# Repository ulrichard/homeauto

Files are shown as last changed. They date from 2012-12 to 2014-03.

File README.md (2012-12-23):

homeauto
========

Remote control power switches from a simple web application.

All you need is :
* Remote switched power plugs that operate at 433MHz
* AtTiny45 http://www.conrad.ch/ce/de/product/154219/
* 433MHz transmitter http://dx.com/p/433mhz-wireless-transmitter-module-superregeneration-for-arduino-green-149254
* A small linux (preferrably debian) device that has ic2 available and can run python. For example: 
		* I use an alix http://pcengines.ch
    	* Also tested with a RaspberryPi http://raspberrypi.org
		* Bifferboard http://bifferos.co.uk/

First flash the code in the directory tiny_i2c_433 onto an AtTiny. The main file RemoteSwitch.c documents how to connect it to the transmitter and the i2c bus.
Once you connected it to the i2c bus of your small linux device, run the python web app homeSwitchWeb.py. It will run on port 5000.
You will have to adjust some settings such as i2c bus address, and rf adressing to match your devices. But it's very simple.

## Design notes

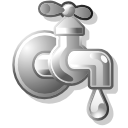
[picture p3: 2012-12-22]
static/C_0.png

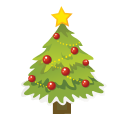
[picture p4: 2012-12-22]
static/B_1.png

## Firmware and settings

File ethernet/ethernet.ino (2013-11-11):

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
#include "IR.h"
#include "nokia3310lcd.h"
#include <EncEthernet.h>
#include <Arduino.h>
#include <Wire.h>
#include <SPI.h>

//  AtMega 328
//                      +-\/-+
//              RST -> 1|    |28 <-  SCL  -------------- C  I
//         uart RXD -> 2|    |27 <-> SDA  -------------- D  2
//         uart TXD <- 3|    |26                   +---- V  C
//  ENC28J60 INT -- D2 4|    |25                   |  +- G 
//      LED red  <- D3 5|    |24                   |  |   nokia 5110 LCD
//                  D4 6|    |23 -> backlight --+  |  |  +--------------+
//                VCC  7|    |22  GND ----------|--|--+--|        GND ->|
//                GND  8|    |21                +--|-----|  backlight ->|
//            crystal  9|    |20  VCC     ---------+-----|        VCC ->|
//            crystal 10|    |19 D13 -> SCK--------------|        SCK ->|  x-> ENC28J60 SCK
//                    11|    |18 D12 <- MISO  +----------|       MOSI ->|  x-> ENC28J60 SO
//                    12|    |17 D11 -> MOSI -+     +----|   cmd/data ->|  x-> ENC28J60 SI
// LCD chip select <- 13|    |16 D10 <- SS          | +--|chip enable ->|  x-> ENC28J60 CS
// LCD reset  |   +-<-14|    |15 D9 -> LCD cmd/data-+ |+-|      reset ->|
//            |   |     +----+                        || +--------------+                  
//            +---|-----------------------------------+|
//                +------------------------------------+  
//
// ENC28J60 Ethernet adapter -> connections from top:
// http://www.geeetech.com/wiki/index.php/Arduino_ENC28J60_Ethernet_Module
// 
// 	  CLK out  |  INT
//	      SOL  |  SO
//         SI  |  SCK
//         CS  |  reset
//        VCC  |  GND

// the mac and ip of the Arduino Ethernet shield
byte mac[] = {0xDE, 0xAD, 0xBE, 0xEF, 0xFE, 0xED};
byte ip[]  = {192, 168, 2, 9};

// Enter the IP address of the web server
byte ulrichardIp[] = {192, 168, 2, 7}; // ulrichard.ch

// pin assignments
static const uint8_t PIN_status_LED = 3;
static const uint8_t PIN_IR_LED     = 9; // OC1A -> infrared transmitter LED.
static const uint8_t LCD_BACKLIGHT  = A0;

EncServer server(80); // Port 80 is http
EncClient ulrichardClient(ulrichardIp, 9332);
Nokia3310LCD  disp(9, 8, 7);

char linebuf[128];
uint16_t linepos;

void setup()
{
	Serial.begin(115200);

	EncEthernet.begin(mac, ip);
	server.begin();

	pinMode(LCD_BACKLIGHT, OUTPUT);
    digitalWrite(LCD_BACKLIGHT, LOW);

//	SPI.begin();
//	SPI.setClockDivider(SPI_CLOCK_DIV64); // 250 kHz

	disp.init();
    disp.LcdContrast(0x40);
	disp.LcdClear();
	disp.LcdGotoXYFont(1, 1);
	disp.LcdStr(Nokia3310LCD::FONT_1X, "hello world");
	disp.LcdUpdate();

//	IR::initialise(0); // IR receiver hardware is on pin2. -> conflicting with ethernet

	pinMode(4, OUTPUT);
	digitalWrite(4, LOW);
	// blink to show we're alive
	pinMode(PIN_status_LED, OUTPUT);
	digitalWrite(PIN_status_LED, HIGH);
	delay(500);
	digitalWrite(PIN_status_LED, LOW);
	delay(500);
	digitalWrite(PIN_status_LED, HIGH);
	delay(500);
	digitalWrite(PIN_status_LED, LOW);
}

void loop()
{
/* -> pin conflicting with ethernet
	// Check if we received some IR code 
	if(!IR::queueIsEmpty())
	{
		digitalWrite(PIN_status_LED, HIGH);
		Serial.println("____");

		IR_COMMAND_TYPE code;
		while(IR::queueRead(code))
		{
			Serial.print("IR: ");
			Serial.println(code, DEC);
		}
		digitalWrite(PIN_status_LED, LOW);
	}
*/

/* first testing the client part
	// Check if we received something over ethernet
	EncClient client = server.available();
	if(client)
	{
//		Serial.println("____");
//		Serial.println("Web: ");

		// an http request ends with a blank line
		boolean current_line_is_blank = true;
		while(client.connected())
		{
			disp.LcdClear();
			uint8_t x = 1, y = 1;

			if(client.available())
			{
				const char c = client.read();
				// if we've gotten to the end of the line (received a newline
				// character) and the line is blank, the http request has ended,
				// so we can send a reply
				if(c == '\n' && current_line_is_blank)
				{
					// send a standard http response header
					client.println("HTTP/1.1 200 OK");
					client.println("Content-Type: text/html");
					client.println();

					// output the value of each analog input pin
					for(int i = 0; i < 6; i++)
					{
						client.print("analog input ");
						client.print(i);
						client.print(" is ");
						client.print(analogRead(i));
						client.println("");
					}
					break;
				}
				if(c == '\n')
				{
					// we're starting a new line
					current_line_is_blank = true;

//					Serial.println("");

					x = 1;
					++y;
				}
				else if(c != '\r')
				{
					// we've gotten a character on the current line
					current_line_is_blank = false;

//					Serial.print(c);
					disp.LcdGotoXYFont(x, y);
					disp.LcdChr(Nokia3310LCD::FONT_1X, c);
				}
			}
			disp.LcdUpdate();
		}
		// give the web browser time to receive the data
		delay(1);
		client.stop();
	}
*/

	// Check the state of the bitcoin miner
	// https://en.bitcoin.it/wiki/P2Pool#Web_interface
	linepos = 0;
	bool foundPrev = false, foundColon = false;
	uint32_t hashrate = 0;
	while(ulrichardClient.connected())
	{
		digitalWrite(PIN_status_LED, LOW);

		if(!ulrichardClient.available())
			continue;
		const char c = ulrichardClient.read();

		if('\n' == c)
		{
			linebuf[linepos++] = '\0';

			if(0 == hashrate)
			{
				disp.LcdGotoXYFont(1, 1);
				disp.LcdStr(Nokia3310LCD::FONT_1X, linebuf);
				disp.LcdUpdate();
			}

			if(foundColon)
			{
				hashrate = atoi(linebuf);         // in H/s
				hashrate /= (1024 * 1024 * 1024); // GH/s

				sprintf(linebuf, "%d GH/s", hashrate);

				disp.LcdGotoXYFont(1, 1);
				disp.LcdStr(Nokia3310LCD::FONT_1X, linebuf);
				disp.LcdUpdate();

				foundColon = foundPrev = false;
			}
			else if(strncmp("miner_hash_rates", linebuf, 16))
				foundPrev = true;


			linepos = 0;
		}
		else if('\r' == c)
			continue;
		else if(0 == linepos && (' ' == c || '*' == c || '\"' == c))
			continue; // trim left
		else if(foundPrev && !foundColon)
		{
			if(':' == c)
				foundColon = true;
			continue;
		}
		else if(linepos + 2 < sizeof(linebuf))
			linebuf[linepos++] = c;
	}
	ulrichardClient.stop();
	delay(10);
		 
	if(ulrichardClient.connect())
	{
		digitalWrite(PIN_status_LED, LOW);
//		Serial.println("ulrichard.ch reachable");

		ulrichardClient.println("GET /local_stats HTTP/1.1");
		ulrichardClient.println("Host: 192.168.2.7:9332");
		ulrichardClient.println();

		
	}
	else
	{
		digitalWrite(PIN_status_LED, HIGH);
//		Serial.println("no connection to ulrichard.ch");

		disp.LcdClear();
		disp.LcdGotoXYFont(1, 1);
		disp.LcdStr(Nokia3310LCD::FONT_1X, "could not");
		disp.LcdGotoXYFont(1, 2);
		disp.LcdStr(Nokia3310LCD::FONT_1X, "connect to");
		disp.LcdGotoXYFont(1, 3);
		disp.LcdStr(Nokia3310LCD::FONT_1X, "ulrichard.ch:9332");
		disp.LcdUpdate();
	}
	

}

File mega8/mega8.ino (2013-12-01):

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
// This program will serve as an interface between the
// the i2c bus and a simple 433MHz transmitter.
// It exposes commands to switch wall plugs
// Created by Richard Ulrich <richi@paraeasy.ch>
// Inspired by :


// ATMEL AtMega8
//                       +-\/-+
//                      1|    |8  Vcc
//                      2|    |7 <-  I2C_SCL
//              test -> 3|    |6  -> 433MHz transmitter
//               GND    4|    |5 <-> I2C_SDA
//                       +----+

#include <inttypes.h>
#include "usiTwiSlave.h"
#include "RemoteTransmitter.h"
#include <avr/io.h>
#include <util/delay.h>
#include <avr/interrupt.h>
#include <avr/eeprom.h>

uint8_t  EEMEM i2cSlaveAddr = 0x11; // Default address

int main(void)
{
	_delay_ms(100); // give the master some time to grab the i2c bus
	sei(); 			// enable interrupts
	if(eeprom_read_byte(&i2cSlaveAddr) < 7 || eeprom_read_byte(&i2cSlaveAddr) > 77)
		eeprom_write_byte(&i2cSlaveAddr, 0x11);
	usiTwiSlaveInit(eeprom_read_byte(&i2cSlaveAddr)); // initialize i2c

	// Set Port B pin 1 as output
	DDRB = (1 << PB1);

	// Intantiate a new Elro remote, also use pin 11 (same transmitter!)
	RemoteTransmitter elroTransmitter;
	InitElroTransmitter(&elroTransmitter, 1 << PB1);

	uint8_t plugAddress = 21;
	uint8_t plugDevice = 'B';

	// the main loop
	while(1)
	{
		// check the test pin
		if(PINB & (1 << PB4))
		{
			ElroSendSignal(&elroTransmitter, plugAddress, 'B', true);
			_delay_ms(1000);
			ElroSendSignal(&elroTransmitter, plugAddress, 'B', false);
			_delay_ms(1000);
		}
	
		// I2C
		if(usiTwiDataInReceiveBuffer())
		{
			const uint8_t cmd = usiTwiReceiveByte();

			switch(cmd)
			{
				case 0xA1: // change the i2c address (sends 1 byte)
				{
					uint8_t recv = usiTwiReceiveByte();
					if(recv < 7 || recv > 77)
						continue;
					eeprom_write_byte(&i2cSlaveAddr, recv);
					usiTwiSlaveInit(recv); // initialize i2c
					break;
				}
				case 0xAA: // set address for switching
					plugAddress = usiTwiReceiveByte();
					break;
				case 0xB0: // switch off
					plugDevice = usiTwiReceiveByte();
                    ElroSendSignal(&elroTransmitter, plugAddress, plugDevice, false);
					break;
				case 0xB1: // switch on
					plugDevice = usiTwiReceiveByte();
					ElroSendSignal(&elroTransmitter, plugAddress, plugDevice, true);
					break;
			}; // switch
			continue;
		}

		_delay_ms(10);
	}

	return 1;
}

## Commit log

2013-09-05 started with the ir sender satellite part that is attached to the etherrnet. Even this most simple example doesn't fit onto an AtMega8
    [ethernet.ino]
2013-09-10 adding the library from http://www.geeetech.com/wiki/index.php/Arduino_ENC28J60_Ethernet_Module
2013-10-02 getting the old library to compile with the current Arduino environment
2013-11-10 adding a display and started querying the miner status
    [homeauto_remote.fzz]
2014-03-25 added channel d for switching the light in the bedroom

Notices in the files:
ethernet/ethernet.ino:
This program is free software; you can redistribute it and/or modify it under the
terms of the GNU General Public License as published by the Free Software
